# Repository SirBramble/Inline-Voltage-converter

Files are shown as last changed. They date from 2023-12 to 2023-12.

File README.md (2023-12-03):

# The Vuwu inline voltage converter

This Project is a small adjustable Buck-Boost converter board, designed to be fitted inline with a Power Cable. It's only 14mmx22mm making it ideal for splicing in to a cable and wrapping it with heat shrink. The connectors used are *2 pin JST PH 2.0 SMD vertical*. A Link to them can be found [here](https://de.aliexpress.com/item/1005004938361514.html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).

## Ordering

The design files for KiCad are located in the folders. Alternatively you can use the GERBER Files with a preconfigured BOM to order them from JLCPCB.

## Setting the Voltage

Due to the small size of the board, adding a potentiometer was not possible.
The output voltage can be set via the $R_4$ Resistor located on the back of the PCB. $R_4$ is calculated as follows:

$$R_4 = R_3 \cdot \left(\frac{V_{OUT}}{V_{REF}} - 1\right) = 10k\Omega \cdot \left(\frac{V_{OUT}}{0.8V} - 1\right)$$

Alternatively there is a small conversion table for common voltages:

|$V_{OUT}$| $R_4$ |
| --- | --- |
|  $3V3$  | $31k\Omega$|
|  $5V$ | $53k\Omega$|
|  $5V3$  | $56k\Omega$|
|  $5V5$  | $59k\Omega$|

**Important:** The [TPS63070](https://www.ti.com/lit/ds/symlink/tps63070.pdf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) only has a output Voltage Rage of $2.5V$ to $9V$ and an approximate max. current of $2A$. For more information, see the [datasheet](https://www.ti.com/lit/ds/symlink/tps63070.pdf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).

## Pictures

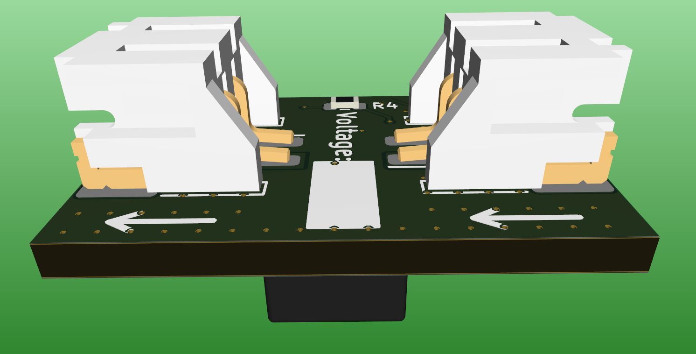
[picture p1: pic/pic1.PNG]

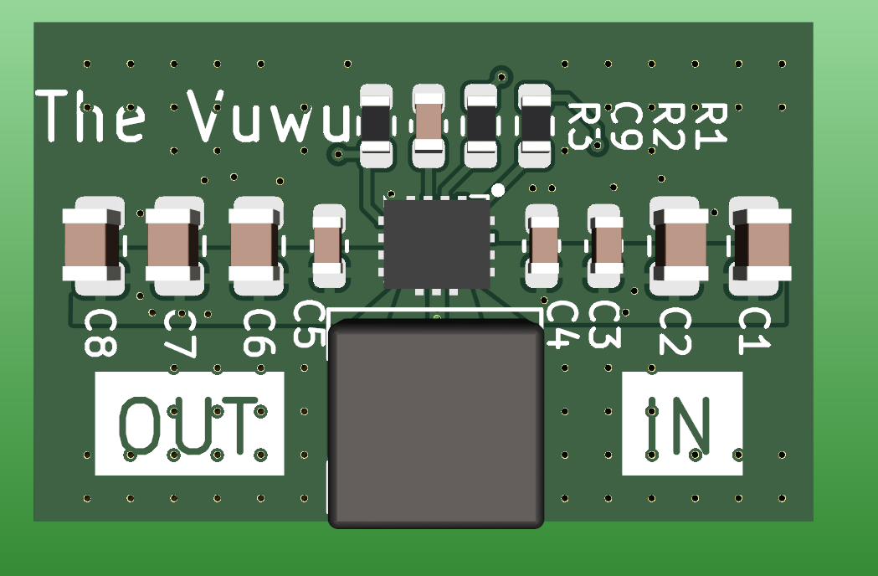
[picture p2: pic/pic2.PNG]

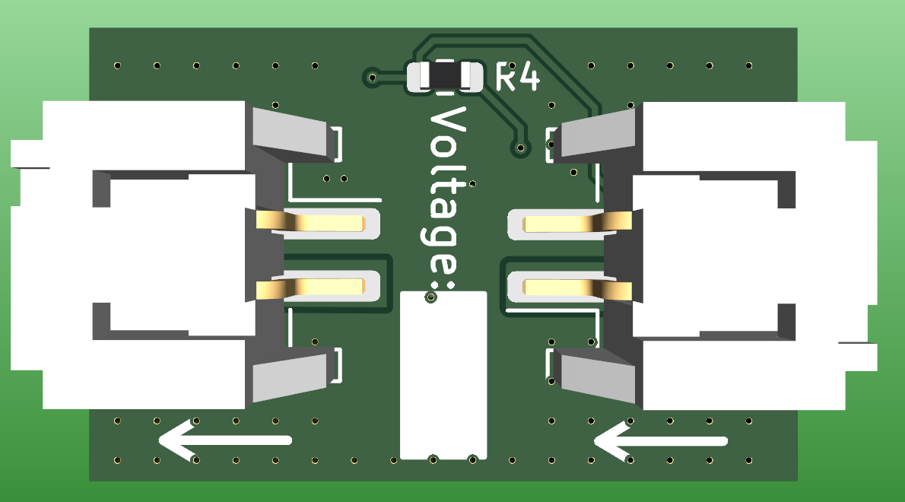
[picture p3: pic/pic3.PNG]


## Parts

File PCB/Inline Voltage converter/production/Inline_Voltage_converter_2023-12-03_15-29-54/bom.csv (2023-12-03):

Designator | Footprint | Quantity | Value | LCSC Part #
C1, C2 | 0805 | 2 | 10uF | C440198
C3, C5 | 0603 | 2 | 10uF | C96446
C4, C9 | 0603 | 2 | 100n | C14663
C6, C7, C8 | 0805 | 3 | 22uF | C45783
IC1 | TPS630701RNMR | 1 | TPS63070RNMR | C109322
L1 | L_Chilisin_BMRA00050530 | 1 | 1.5uH | C436532
R1, R3 | 0603 | 2 | 10k | C25804
R2 | 0603 | 1 | 100k | C25803

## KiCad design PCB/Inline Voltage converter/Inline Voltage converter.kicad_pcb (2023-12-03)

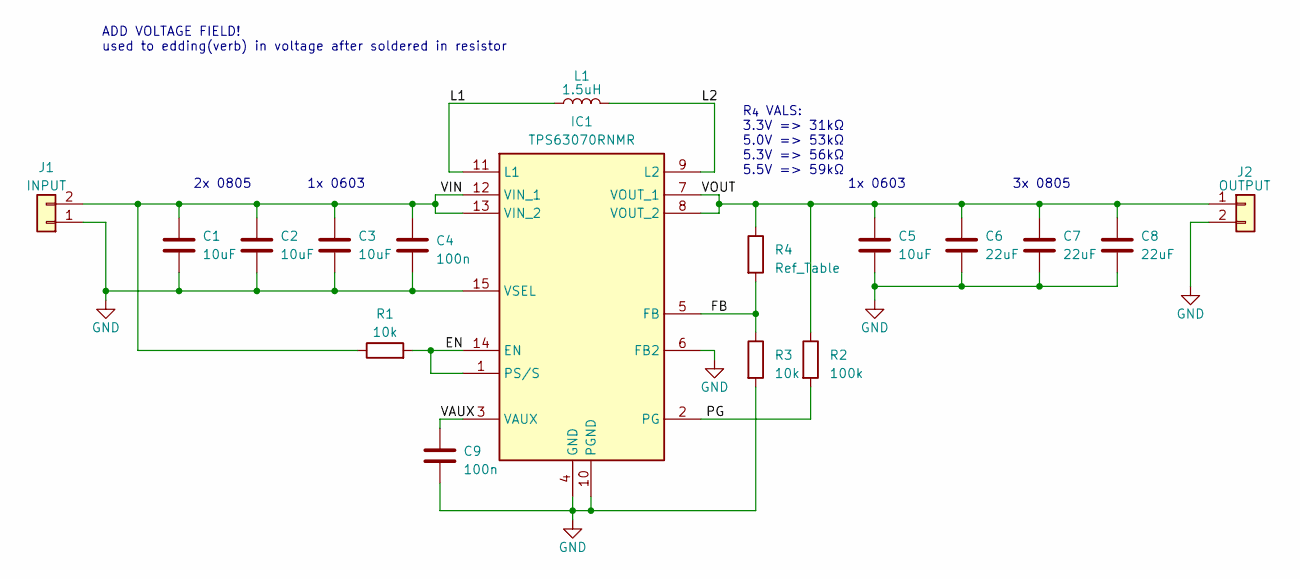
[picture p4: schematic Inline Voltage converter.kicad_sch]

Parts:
C1, C2: 10uF; C_0805_2012Metric; LCSC C440198
C3, C5: 10uF; C_0603_1608Metric; LCSC C96446
C4, C9: 100n; C_0603_1608Metric; LCSC C14663
C6, C7, C8: 22uF; C_0805_2012Metric; LCSC C45783
IC1: TPS63070RNMR; TPS630701RNMR; Mouser Part Number 595-TPS63070RNMR
J1: INPUT; JST_PH_S2B-PH-SM4-TB_1x02-1MP_P2.00mm_Horizontal
J2: OUTPUT; JST_PH_S2B-PH-SM4-TB_1x02-1MP_P2.00mm_Horizontal
L1: 1.5uH; L_Chilisin_BMRA00050530; LCSC C436532
R1, R3: 10k; R_0603_1608Metric; LCSC C25804
R2: 100k; R_0603_1608Metric; LCSC C25803
R4: Ref_Table; R_0603_1608Metric

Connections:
/EN: IC1.1 (PS/S), IC1.14 (EN), R1.2
/FB: IC1.5 (FB), R3.1, R4.2
/L1: IC1.11 (L1), L1.1
/L2: IC1.9 (L2), L1.2
/PG: IC1.2 (PG), R2.2
/VAUX: C9.1, IC1.3 (VAUX)
/VIN: C1.1, C2.1, C3.1, C4.1, IC1.12 (VIN_1), IC1.13 (VIN_2), J1.2, R1.1
/VOUT: C5.1, C6.1, C7.1, C8.1, IC1.7 (VOUT_1), IC1.8 (VOUT_2), J2.1, R2.1, R4.1
GND: C1.2, C2.2, C3.2, C4.2, C5.2, C6.2, C7.2, C8.2, C9.2, IC1.4 (GND), IC1.6 (FB2), IC1.10 (PGND), IC1.15 (VSEL), J1.1, J2.2, R3.2

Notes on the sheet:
2x 0805 1x 0603
R_{4} VALS: 3.3V => 31kΩ 5.0V => 53kΩ 5.3V => 56kΩ 5.5V => 59kΩ
1x 0603
ADD VOLTAGE FIELD! used to edding(verb) in voltage after soldered in resistor
3x 0805

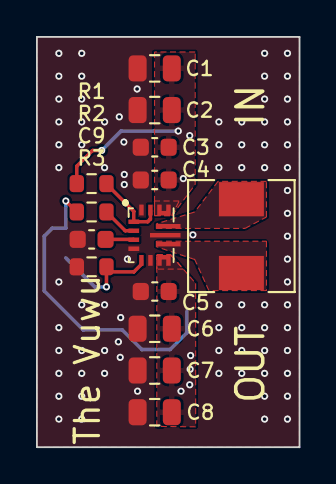
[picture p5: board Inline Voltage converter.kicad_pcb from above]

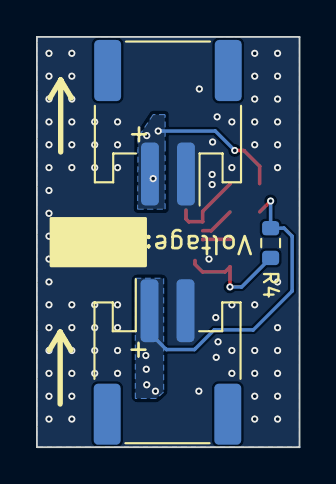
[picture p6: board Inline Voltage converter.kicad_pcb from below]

Board: 2 copper layers, 14.6 x 22.8 mm, 17 parts (3 on the bottom side), 9 nets.
